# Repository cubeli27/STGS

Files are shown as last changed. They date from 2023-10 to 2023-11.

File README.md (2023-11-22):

# STGS
##### See-Through Glass Sensor
## Power management and switching hub 

My wish was to keep this board as reusable as possible as well as have it still flexible enough if in the future conditions where it is supposed to work change. It's safe to say I prioritized the current application for what is intended for over-reusability. The only reason this board exists is that a dear professor of mine wishes to upgrade the glass display in front of the electronics lab but the power bank that powers (currently 2) devices runs out every day and it is tedious to replace it constantly. Also having devices turned on all the time when most of the time no one is looking is unproductive. 

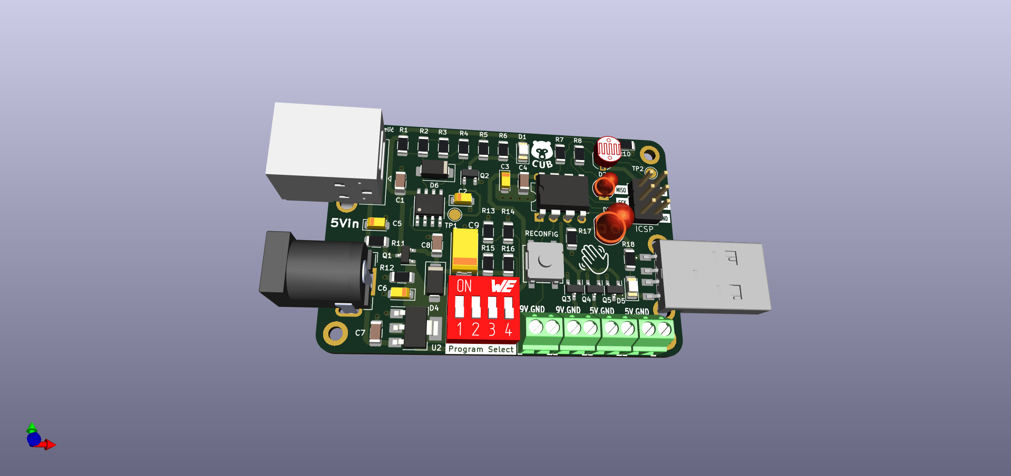
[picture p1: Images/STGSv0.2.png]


# Problems/Solutions
For aesthetic reasons, the requirement was for the board to be inside the glass display and no wires or parts are outside to turn on the devices. 
My solution for this was a simple yet effective combination of LDR and infra-red led & diode pair. Hence it can be triggered from outside the glass as well as benefiting the whole experience as other students can interact with the display.

The setup is currently supplied by a power bank as there are no outlets in the display. Power banks turn off after a few seconds or more up to 20-30s when not enough current is being drawn usually around 100mA but these values depend on the specific power bank. To overcome this my solution was to use ICM7555 in astable mode with a diode for a duty cycle less than 50%. As my power bank turns off at under ~30 seconds for the sake of having a safety factor the circuit is designed to give a pulse every 21s and drawing about 33mA for 0.7s and this seems to work nicely.  Of course, this feature is only active when the board is powered through USB. There is also a DC Barrel Jack I decided should be available. I thought a power management board should have at least two ways of inputting power. This way if in the future the location of the display changes and there is a wall outlet available the whole display can be powered with a 9V power adapter, as well as giving flexibility if ex. an upcoming student project that will be displayed needs more than 5V. Also, a little safety feature was added an auto selector in case someone accidentally connects both the USB and DC jack so nothing bad will happen. 

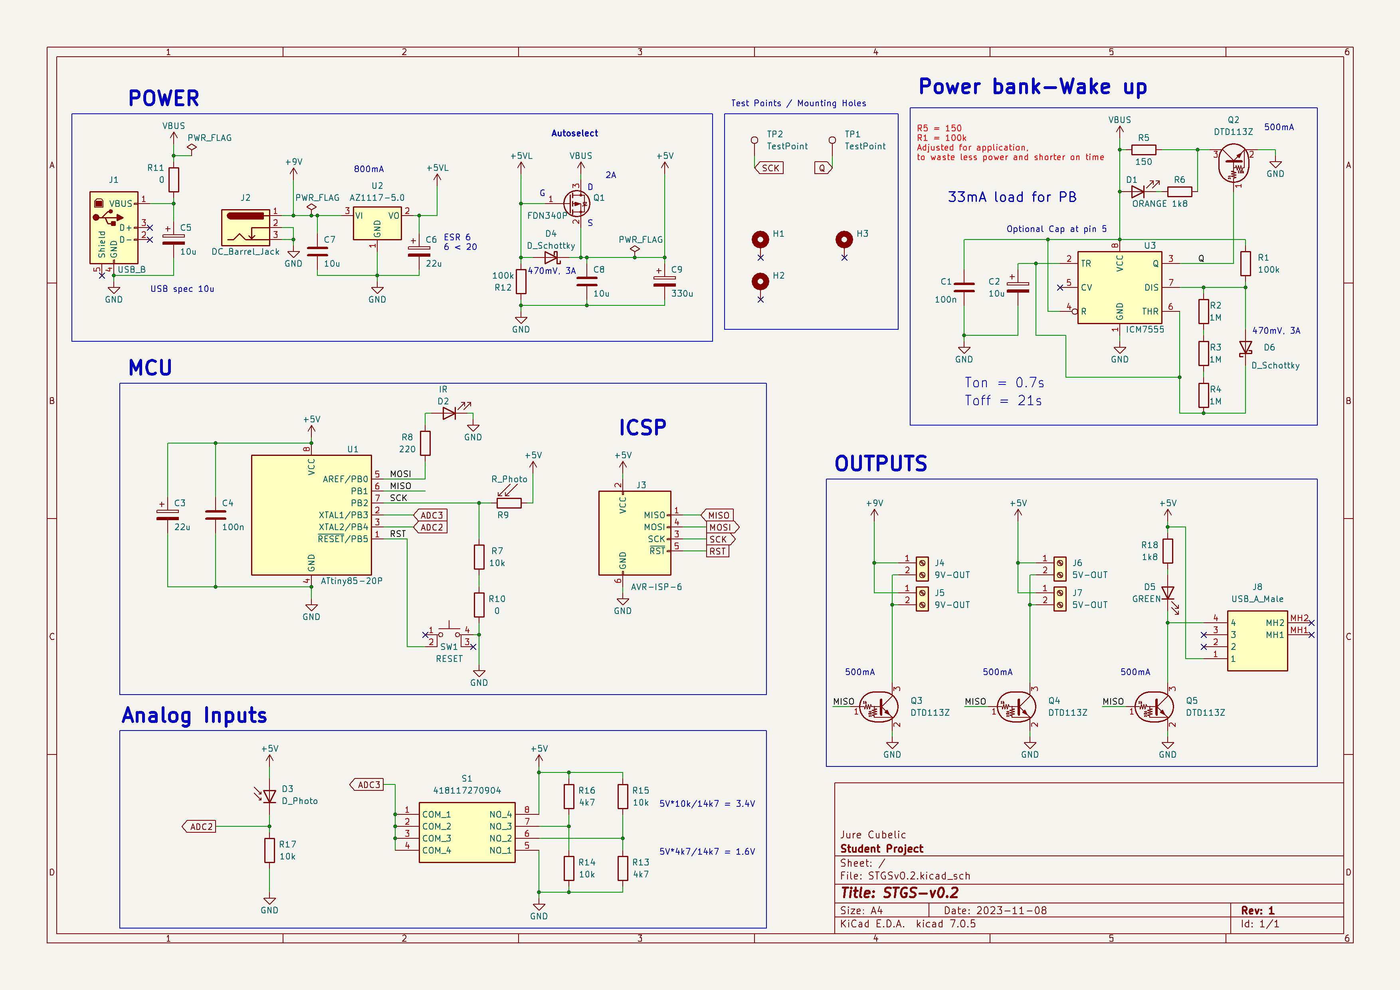
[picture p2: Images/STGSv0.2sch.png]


Power bank: 10,000mAh 

Average consumption: 4mA

So now instead of changing the power bank every day regardless of visitation, idealistically the power bank should be able to work 2500 hours which is around 100 days. Of course, this is without anyone passing by ever and turning it on, and nothing in the real world is ideal. 

From 1 day to 100 days is two orders of magnitude difference. As already mentioned factors, I am happy with even one order of magnitude, and in case the power bank needs to be changed every 10 days as well as provide an interactive display for visitors it is useful and beneficial. 



The code provided is functional but not optimal, but it works. I will revisit this as soon as I get some time.

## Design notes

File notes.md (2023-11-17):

# STGS
ATtiny85 datasheet, page 161
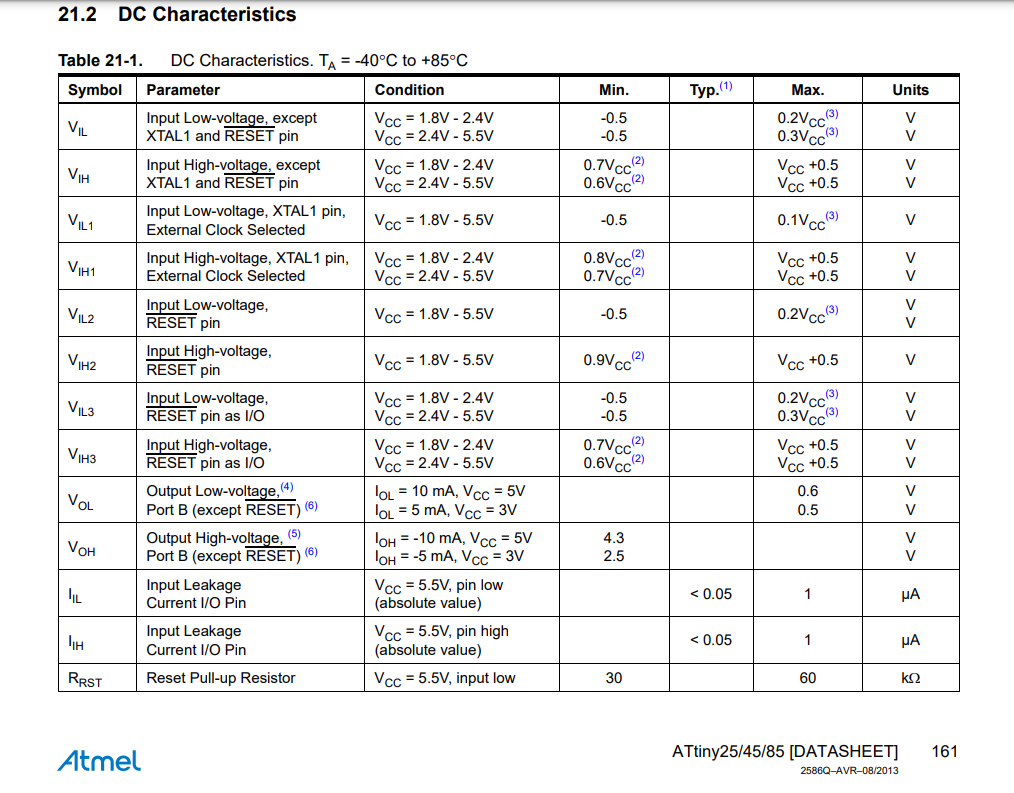
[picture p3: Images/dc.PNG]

To use external interrupt I need logic zero which is max 0.3* Vcc
Otherwise, logic 1 is min 0.6* Vcc

Photo resistor ambient resistance = 25k //arduino kit 

Dark = 150-300k 

Voltage divider rule 
R = 58k //in house 

R = 2k2 //in lab 

R = 10k // in hallway for the P_Resistor available in lab, for PCB manufactured in lab 

R = 6k8 works best for ordered PCB

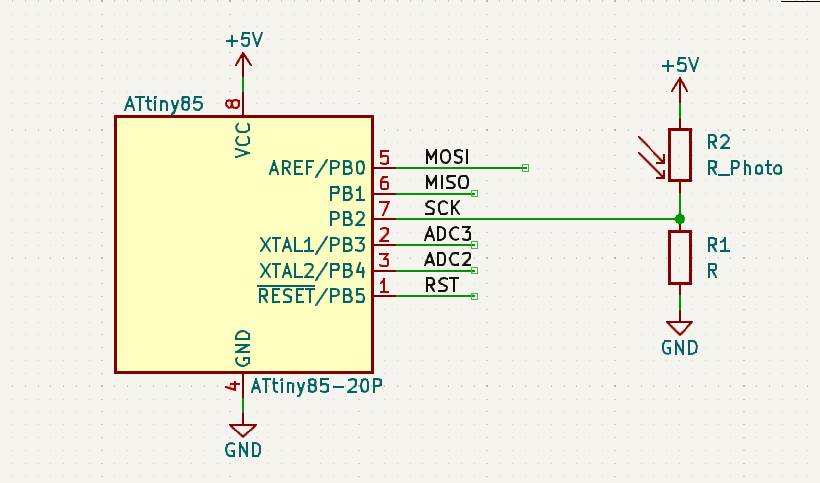
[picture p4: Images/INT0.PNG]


7.1.3 Power-down Mode

When the SM[1:0] bits are written to 10, the SLEEP instruction makes the MCU enter Power-down mode. In this
mode, the Oscillator is stopped, while the external interrupts, the USI start condition detection and the Watchdog
continue operating (if enabled). Only an External Reset, a Watchdog Reset, a Brown-out Reset, USI start condition
interupt, an external level interrupt on INT0 or a pin change interrupt can wake up the MCU. This sleep mode halts
all generated clocks, allowing operation of asynchronous modules only

Power bank Issue: 
Time before turn off 35s.
Need to draw more current so the power bank stays on.
Solution: 20s off, 1 second on with 150mA
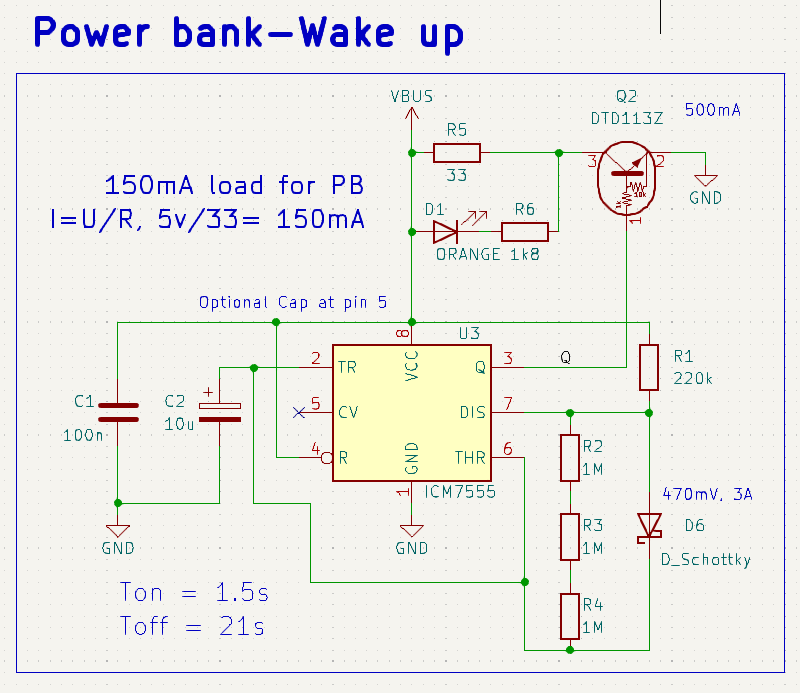
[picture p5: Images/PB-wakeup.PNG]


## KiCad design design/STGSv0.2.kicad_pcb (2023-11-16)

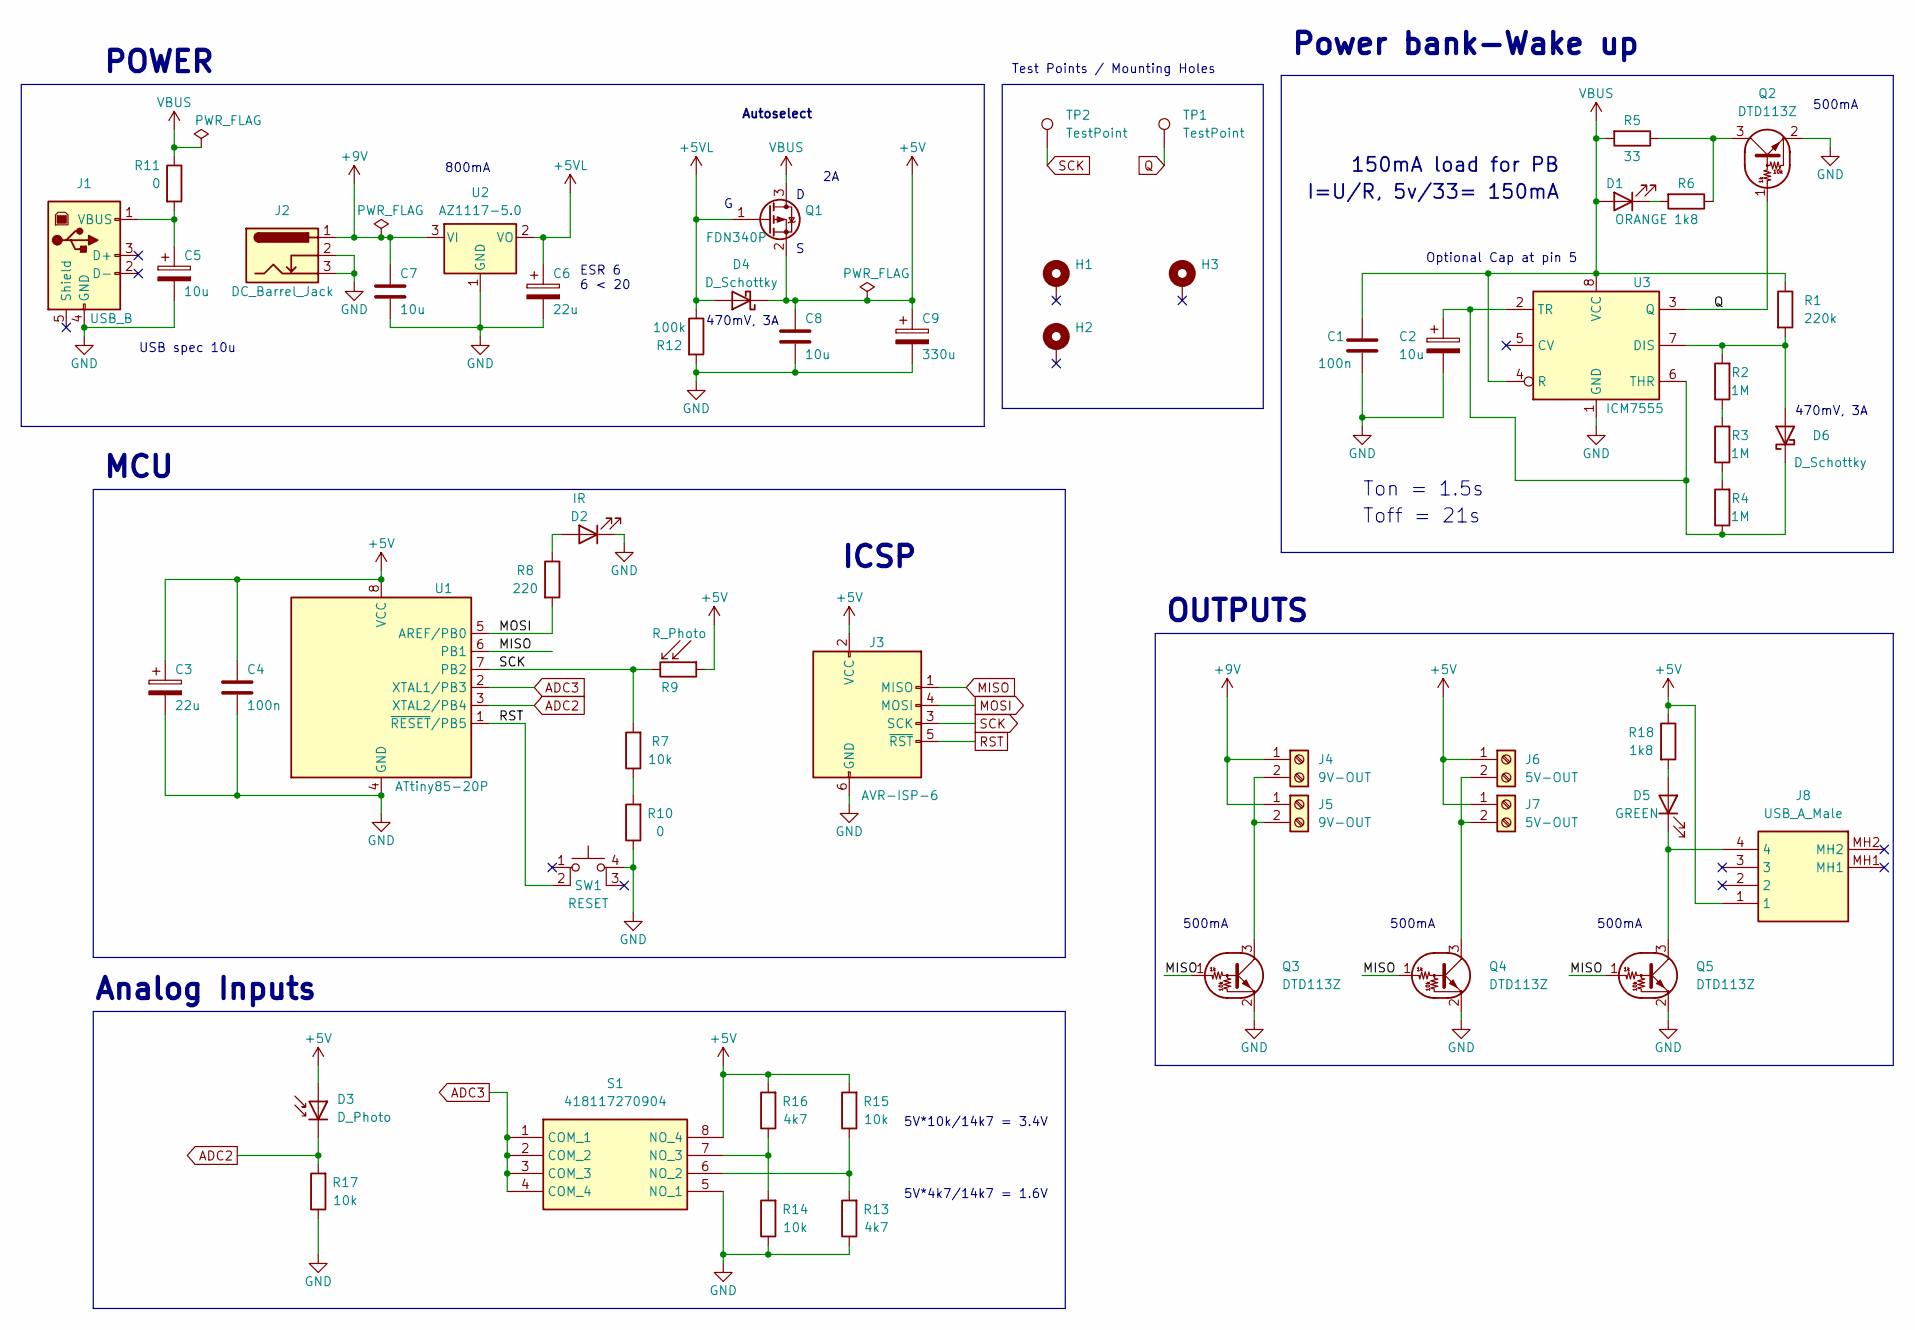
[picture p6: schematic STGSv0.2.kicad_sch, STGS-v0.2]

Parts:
C1, C4: 100n; C_1206_3216Metric
C2, C5: 10u; CP_EIA-3216-18_Kemet-A
C3, C6: 22u; CP_EIA-3216-18_Kemet-A
C7, C8: 10u; C_1206_3216Metric
C9: 330u; CP_EIA-7343-31_Kemet-D
D1: ORANGE; LED_1206_3216Metric
D2: IR; LED_D3.0mm
D3: D_Photo; LED_D5.0mm
D4, D6: D_Schottky; D_SMA
D5: GREEN; LED_1206_3216Metric
H1, H2, H3: MountingHole_Pad; MountingHole_2.2mm_M2_DIN965_Pad_TopBottom
J1: USB_B; USB_B_OST_USB-B1HSxx_Horizontal
J2: DC_Barrel_Jack; BarrelJack_GCT_DCJ200-10-A_Horizontal
J3: AVR-ISP-6; PinHeader_2x03_P2.54mm_Vertical
J4, J5: 9V-OUT; 1725656
J6, J7: 5V-OUT; 1725656
J8: USB_A_Male; 480372100; Mouser Part Number 538-48037-2100
Q1: FDN340P; SOT-23
Q2, Q3, Q4, Q5: DTD113Z; SOT-23-3
R1: 220k; R_1206_3216Metric
R2, R3, R4: 1M; R_1206_3216Metric
R5: 33; R_1206_3216Metric
R6, R18: 1k8; R_1206_3216Metric
R7, R14, R15, R17: 10k; R_1206_3216Metric
R8: 220; R_1206_3216Metric
R9: R_Photo; XDCR_PDV-P9003-1
R10, R11: 0; R_1206_3216Metric
R12: 100k; R_1206_3216Metric
R13, R16: 4k7; R_1206_3216Metric
S1: 418117270904; Mouser Part Number 710-418117270904
SW1: RESET; SW_B3SL-1002P_OMR
TP1, TP2: TestPoint; TestPoint_Pad_D2.0mm
U1: ATtiny85-20P; DIP-8_W7.62mm
U2: AZ1117-5.0; SOT-223-3_TabPin2
U3: ICM7555; SOIC-8_3.9x4.9mm_P1.27mm

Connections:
+5V: C3.1, C4.1, C8.1, C9.1, D3.2 (A), D4.1 (K), J3.2 (VCC), J6.1, J7.1, J8.1, Q1.2 (S), R9.1, R15.2, R16.2, R18.1, S1.8 (NO_4), U1.8 (VCC)
+5VL: C6.1, D4.2 (A), Q1.1 (G), R12.1, U2.2 (VO)
+9V: C7.1, J2.1, J4.1, J5.1, U2.3 (VI)
ADC2: D3.1 (K), R17.2, U1.3 (XTAL2/PB4)
ADC3: S1.1 (COM_1), S1.2 (COM_2), S1.3 (COM_3), S1.4 (COM_4), U1.2 (XTAL1/PB3)
GND: C1.2, C2.2, C3.2, C4.2, C5.2, C6.2, C7.2, C8.2, C9.2, D2.1 (K), J1.4 (GND), J2.2, J2.3, J3.6 (GND), Q2.2 (E), Q3.2 (E), Q4.2 (E), Q5.2 (E), R10.1, R12.2, R13.1, R14.1, R17.1, S1.5 (NO_1), SW1.4 (A), U1.4 (GND), U2.1 (GND), U3.1 (GND)
MISO: J3.1 (MISO), Q3.1 (B), Q4.1 (B), Q5.1 (B), U1.6 (PB1)
MOSI: J3.4 (MOSI), R8.2, U1.5 (AREF/PB0)
unnamed: D1.1 (K), R6.2
unnamed: D2.2 (A), R8.1
unnamed: D5.2 (A), R18.2
unnamed: D5.1 (K), J8.4, Q5.3 (C)
unnamed: D6.2 (A), R1.2, R2.2, U3.7 (DIS)
unnamed: C2.1, D6.1 (K), R4.1, U3.2 (TR), U3.6 (THR)
unnamed: C5.1, J1.1 (VBUS), R11.2
unnamed: J4.2, J5.2, Q3.3 (C)
unnamed: J6.2, J7.2, Q4.3 (C)
unnamed: Q2.3 (C), R5.1, R6.1
unnamed: R2.1, R3.2
unnamed: R3.1, R4.2
unnamed: R7.1, R10.2
unnamed: R13.2, R15.1, S1.6 (NO_2)
unnamed: R14.2, R16.1, S1.7 (NO_3)
Q: Q2.1 (B), TP1.1, U3.3 (Q)
RST: J3.5 (~RST), SW1.2, U1.1 (~RESET/PB5)
SCK: J3.3 (SCK), R7.2, R9.2, TP2.1, U1.7 (PB2)
VBUS: C1.1, D1.2 (A), Q1.3 (D), R1.1, R5.2, R11.1, U3.4 (R), U3.8 (VCC)

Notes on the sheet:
500mA
800mA
Ton = 1.5s
Test Points / Mounting Holes
ICSP
Power bank-Wake up
5V*10k/14k7 = 3.4V
I=U/R, 5v/33= 150mA
Autoselect
POWER
Toff = 21s
470mV, 3A
ESR 6 6 < 20
OUTPUTS
150mA load for PB
5V*4k7/14k7 = 1.6V
Analog Inputs
MCU
USB spec 10u
Optional Cap at pin 5

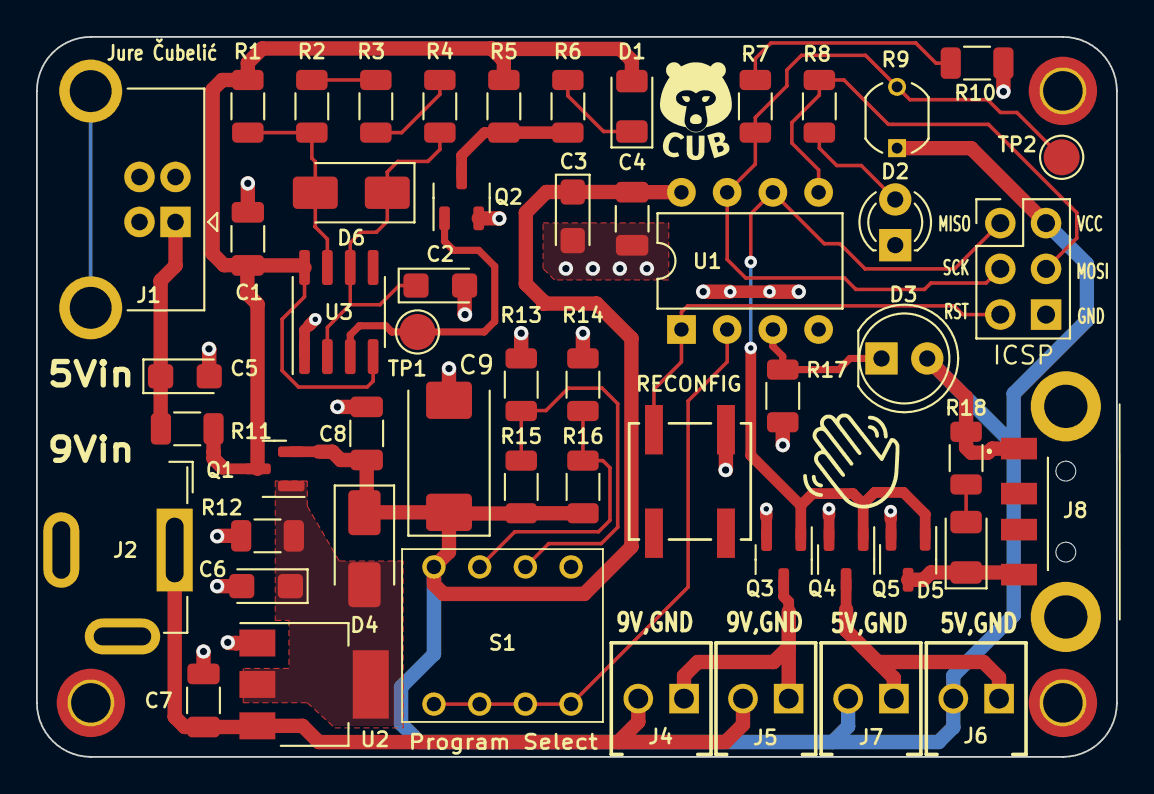
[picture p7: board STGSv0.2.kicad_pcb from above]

Board: 2 copper layers, 60.0 x 40.0 mm, 56 parts (0 on the bottom side), 27 nets.

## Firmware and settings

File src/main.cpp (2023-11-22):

#include<avr/io.h>
#include<avr/interrupt.h>
#include<util/delay.h>
#include <avr/sleep.h>

volatile uint16_t ontime = 0; 
volatile uint16_t proximity = 0;

void init() {
    DDRB |= (1 << PB1); // (ON SWITCH NPN)
    DDRB |= (1 << PB0); // (IR LED)
    DDRB &= ~(1 << PB2); // Interupt pin
    ADCSRA &= ~(1 << ADEN); // Disable ADC

}

void enter_power_down()
{  
  sei();
  MCUCR |= (1 << SM1);      // Enabling powerdown sleep mode, SM[1:0] bits are written to 10
  MCUCR |= (1 << SE);     //Enabling sleep enable bit SLEEP ENABLE
  sleep_cpu();       //__asm__ __volatile__ ( "sleep" "\n\t" :: ); //Sleep instruction in assembly code
}

void enter_idle()
{
  sei();
  MCUCR &= ~(1 << SM1); // Enabling idle sleep mode, SM[1:0] bits are written to 00
  MCUCR |= (1 << SE);     //Enabling sleep enable bit SLEEP ENABLE
  sleep_cpu();           //sleep_mode(); macro might cause race conditions
}

int rxir()
{ // ADC2 for IR reciever
  ADMUX  |= (1 << MUX1) ; //ADC2(PB4) single ended input
  ADCSRA |= (1 << ADEN); // Enable ADC
  ADCSRA |= (1 << ADSC); // Start conversion
  while (ADCSRA & (1 << ADSC)); // Wait for conversion to finish
  return ADC; // Return ADC value 
}
int duration()
{   // ADC3 for potentiometer
  ADMUX &= ~(1 << REFS1) | (1 << REFS0); // Vcc a Aref
  ADMUX = (1 << MUX0) | (1 << MUX1); // Use ADC3 as input
  ADCSRA |= (1 << ADEN); // Enable ADC
  ADCSRA |= (1 << ADSC); // Start conversion
  while (ADCSRA & (1 << ADSC)); // Wait for conversion to finish
  ADMUX = 0x00; // Clears all bits in ADMUX, effectively disabling specific channel selection
  return ADC; // Return ADC value
}

int main(void)
{
  init(); // Initialize the pins
  ontime = duration(); // done only once during startup
  
  while(1){
    PORTB |= (1 << PB0); // IR Led ON
    _delay_ms(100);
    proximity = rxir();
    if(proximity > 300){
      PORTB |= (1<<PB1);      //Turn ON SWITCH
      PORTB &= ~(1 << PB0);   //Turn OFF IR
      for(uint16_t i=0;i < ontime;i++){ // Duration  //TODO Program Select
        _delay_ms(20);
      }
    }
    PORTB &= ~(1 << PB0);   //Turn OFF IR 
    PORTB &= ~(1 << PB1);   //Turn OFF SWITCH
    _delay_ms(10);
    if (PORTB &(1 << PB2)){ //conditions = external interupt not available 
      //enter_idle();        // TODO
      //_delay_ms(5000);
    }
    else if(~PORTB &(1 << PB2)){ //PB2 is HIGH or LIGHT = external interrupt available  
      GIMSK |= (1 << INT0); // Enable INT0 external interupt
      enter_power_down();        // configuration for power down sleep mode
      GIMSK &= ~(1 << INT0); //disable INT0 otherwise interupts rxir(); i think
    }
  }
  return 0;
}

ISR (INT0_vect)        // Interrupt service routine (WAKE UP)
{ // 50k home, 2k2 lab, ~10k hallway = photoresistor pullup @ PB2=INT0=PB2,  6k8 final (false positive priority)
  cli();                // dissable global interrupts, good practice?
  MCUCR &= ~(1 << SE);     //Clear sleep bit as per datasheet SLEEP DISABLE
  uint8_t timeoutCounter = 0; // Initialize the counter
  while (~PINB & (1 << PB2) && timeoutCounter<100) // Wait for button release
  {
    _delay_ms(1); // Small delay to control the loop speed
    timeoutCounter++; 
  } 
}
